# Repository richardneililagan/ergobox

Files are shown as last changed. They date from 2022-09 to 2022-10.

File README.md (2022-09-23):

Ergobox: Hitbox-style fightstick
===

> **NOTE: Work in progress.**
>
> This is not yet ready for build.

Ergobox is a low-profile hitbox-style fightstick based off of
[Flatbox rev4][flatbox-rev4].

This project wants to introduce the following changes / adjustments:

- a more ergonomic button layout
- RGB LED lighting
- adjustments to case to allow for easy personalization

while maintaining some key characteristics that make Flatbox great 
in my opinion:

- low-profile build using Kailh switches
- hotswappable switches
- USB-C port 
- no need for an addon board
- compatibility with [RP2040][rp2040] (so we can use, say, [GP2040-CE][gp2040ce] as firmware)
- ready-to-use artifacts for manufacturing

## Credits and thanks

I'd like to express my gratitude to the following projects,
which Ergobox uses as well:

- [Flatbox][flatbox]
- [keyswitch-kicad-library][keyswitch-kicad-library]
- [Type-C.pretty][typec-pretty]
- [CrumpPrints.pretty][crumpprints-pretty]

## License

This project is licensed under GPLv3.
See [LICENSE](./LICENSE) for the full license text.

[flatbox]: https://github.com/jfedor2/flatbox
[flatbox-rev4]: https://github.com/jfedor2/flatbox/tree/master/hardware-rev4
[rp2040]: https://www.raspberrypi.com/documentation/microcontrollers/rp2040.html
[gp2040ce]: https://github.com/OpenStickFoundation/GP2040-CE

[keyswitch-kicad-library]: https://github.com/perigoso/keyswitch-kicad-library
[typec-pretty]: https://github.com/ai03-2725/Type-C.pretty
[crumpprints-pretty]: https://github.com/tylercrumpton/CrumpPrints.pretty

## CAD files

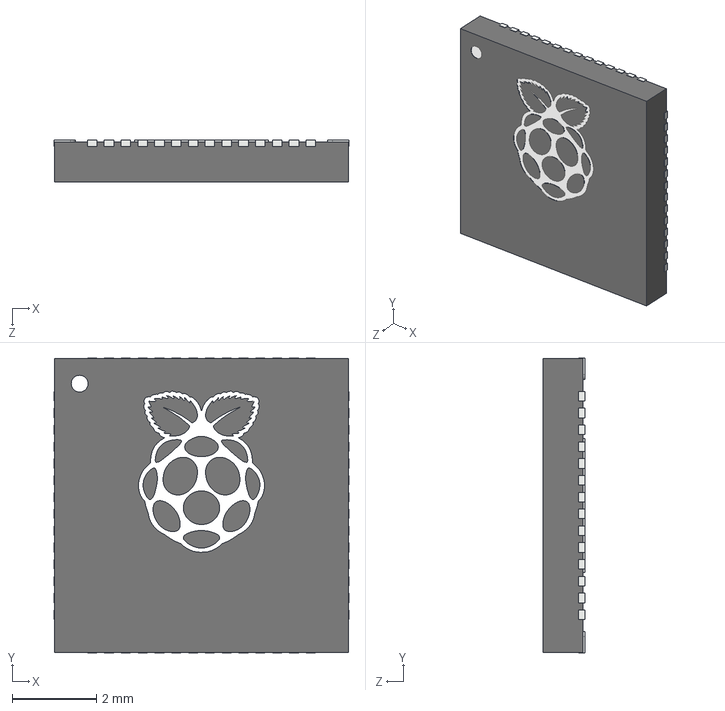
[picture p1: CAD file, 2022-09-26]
pcb/kicad/includes/models/RP2040_QFN_PACKAGE.STEP
7.02 x 7.02 x 1.00 mm

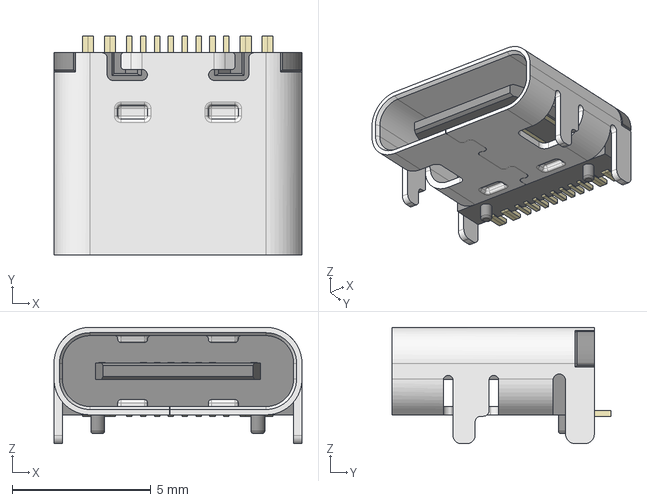
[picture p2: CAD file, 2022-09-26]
pcb/kicad/includes/models/HRO_TYPE-C-31-M-12.step
8.95 x 7.90 x 4.20 mm

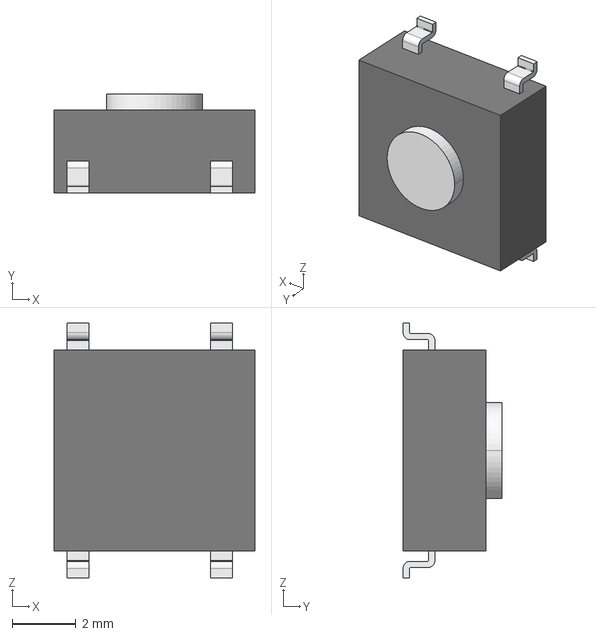
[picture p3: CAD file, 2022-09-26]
pcb/kicad/includes/models/b3fs-1000p.stp
6.30 x 3.10 x 8.00 mm

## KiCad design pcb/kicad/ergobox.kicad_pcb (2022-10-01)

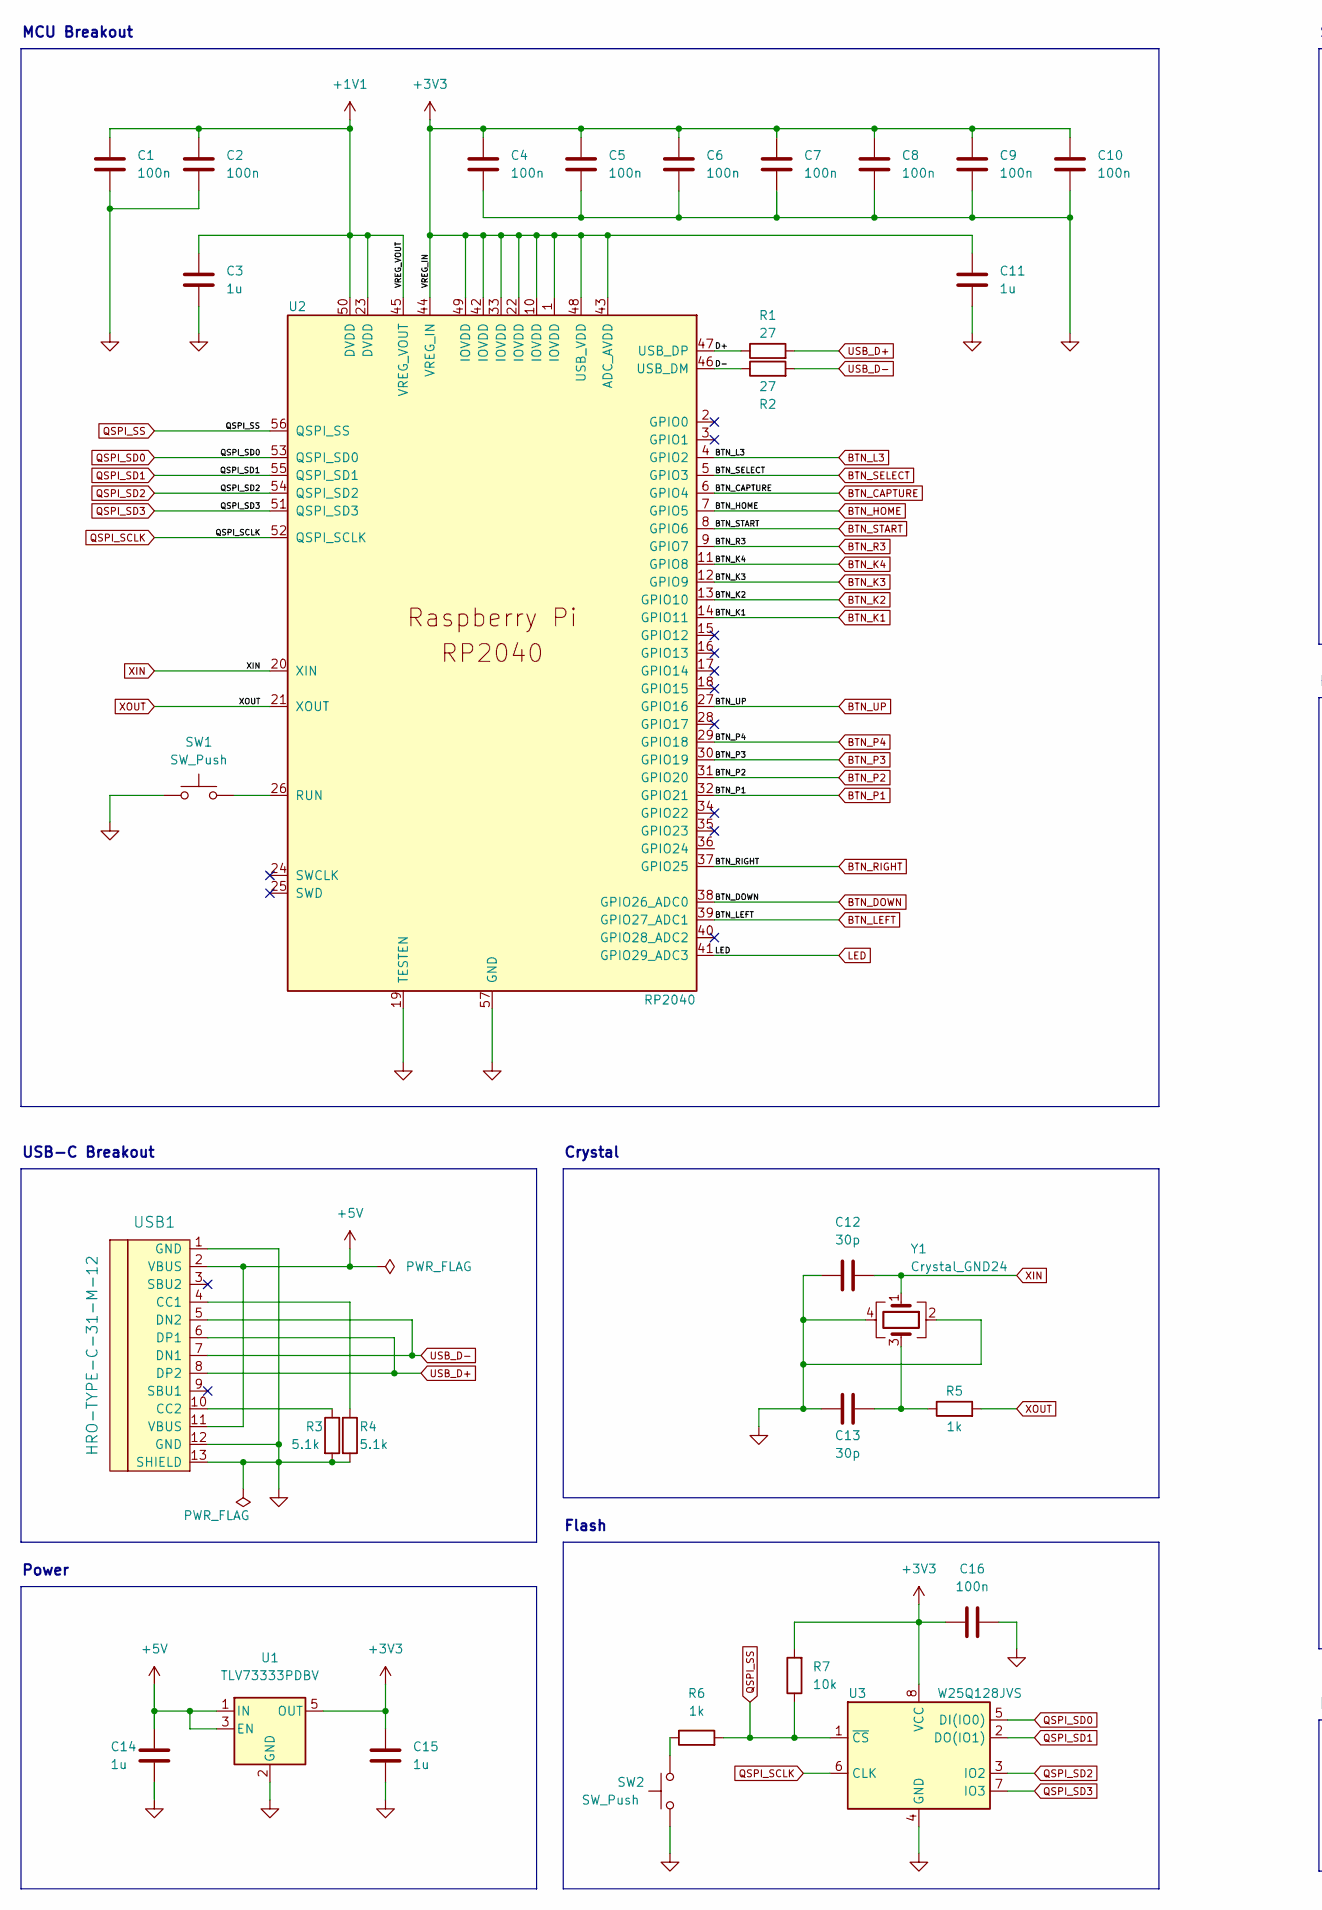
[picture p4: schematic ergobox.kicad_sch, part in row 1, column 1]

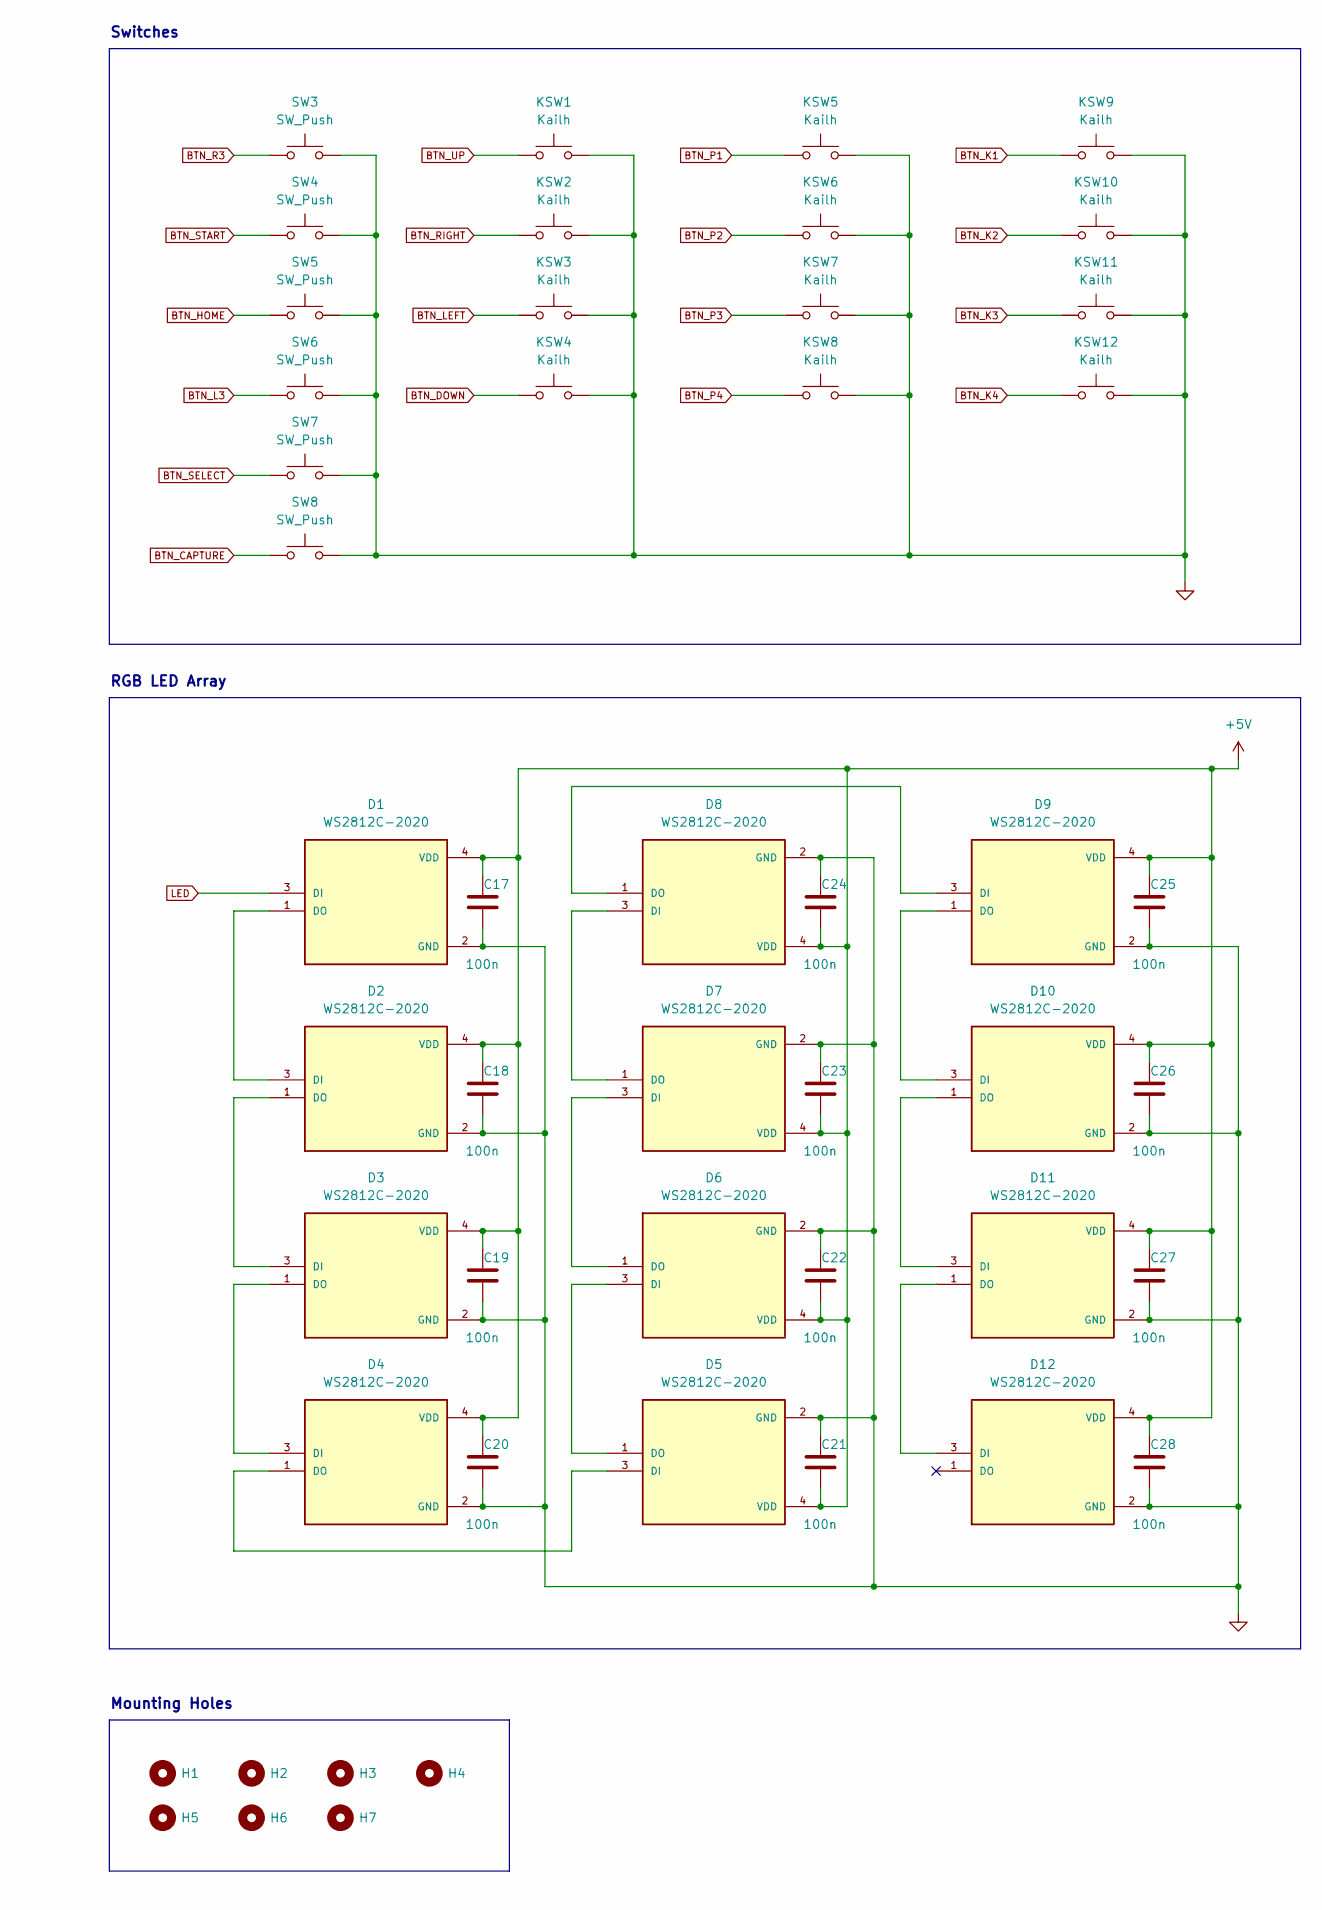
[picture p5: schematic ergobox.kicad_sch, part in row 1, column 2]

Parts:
C1, C2, C4, C5, C6, C7, C8, C9, C10, C16: 100n; C_0402_1005Metric; LCSC C1525
C3, C11, C14, C15: 1u; C_0402_1005Metric; LCSC C52923
C12, C13: 30p; C_0402_1005Metric; LCSC C1570
C17, C18, C19, C20, C21, C22, C23, C24, C25, C26, C27, C28: 100n; C_0402_1005Metric; LCSC C52923
D1, D2, D3, D4, D5, D6, D7, D8, D9, D10, D11, D12: WS2812C-2020; LED_WS2812C-2020; PARTREV V1.0; LCSC C2976072
H1, H2, H3, H4, H5, H6, H7: MountingHole; MountingHole_3.2mm_M3
KSW1, KSW2, KSW3, KSW4, KSW5, KSW6, KSW7, KSW8, KSW9, KSW10, KSW11, KSW12: Kailh; SW_Hotswap_Kailh_Choc_V1V2; JLCPCB_IGNORE true
R1, R2: 27; R_0402_1005Metric; LCSC C138021
R3, R4: 5.1k; R_0402_1005Metric; LCSC C25905
R5, R6: 1k; R_0402_1005Metric; LCSC C11702
R7: 10k; R_0402_1005Metric; LCSC C25744
SW1, SW2: SW_Push; SW_SPST_Omron_B3FS-100xP; LCSC C271750
SW3, SW4, SW5, SW6, SW7, SW8: SW_Push; SW_PUSH_6mm_H5mm; LCSC C620304
U1: TLV73333PDBV; SOT-23-5; LCSC C134139
U2: RP2040; RP2040-QFN-56; LCSC C2040
U3: W25Q128JVS; SOIC-8_5.23x5.23mm_P1.27mm; LCSC C97521
USB1: HRO-TYPE-C-31-M-12; LCSC C165948
Y1: Crystal_GND24; Crystal_SMD_3225-4Pin_3.2x2.5mm; LCSC C9002

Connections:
+1V1: C1.1, C2.1, C3.1, U2.23 (DVDD), U2.45 (VREG_VOUT), U2.50 (DVDD)
+3V3: C4.1, C5.1, C6.1, C7.1, C8.1, C9.1, C10.1, C11.1, C15.1, C16.1, R7.2, U1.5 (OUT), U2.1 (IOVDD), U2.10 (IOVDD), U2.22 (IOVDD), U2.33 (IOVDD), U2.42 (IOVDD), U2.43 (ADC_AVDD), U2.44 (VREG_IN), U2.48 (USB_VDD), U2.49 (IOVDD), U3.8 (VCC)
+5V: C14.1, C17.1, C18.1, C19.1, C20.1, C21.2, C22.2, C23.2, C24.2, C25.1, C26.1, C27.1, C28.1, D1.4 (VDD), D2.4 (VDD), D3.4 (VDD), D4.4 (VDD), D5.4 (VDD), D6.4 (VDD), D7.4 (VDD), D8.4 (VDD), D9.4 (VDD), D10.4 (VDD), D11.4 (VDD), D12.4 (VDD), U1.1 (IN), U1.3 (EN), USB1.2 (VBUS), USB1.11 (VBUS)
/D+: R1.1, U2.47 (USB_DP)
/D-: R2.1, U2.46 (USB_DM)
BTN_CAPTURE: SW8.1, U2.6 (GPIO4)
BTN_DOWN: KSW4.1, U2.38 (GPIO26_ADC0)
BTN_HOME: SW5.1, U2.7 (GPIO5)
BTN_K1: KSW9.1, U2.14 (GPIO11)
BTN_K2: KSW10.1, U2.13 (GPIO10)
BTN_K3: KSW11.1, U2.12 (GPIO9)
BTN_K4: KSW12.1, U2.11 (GPIO8)
BTN_L3: SW6.1, U2.4 (GPIO2)
BTN_LEFT: KSW3.1, U2.39 (GPIO27_ADC1)
BTN_P1: KSW5.1, U2.32 (GPIO21)
BTN_P2: KSW6.1, U2.31 (GPIO20)
BTN_P3: KSW7.1, U2.30 (GPIO19)
BTN_P4: KSW8.1, U2.29 (GPIO18)
BTN_R3: SW3.1, U2.9 (GPIO7)
BTN_RIGHT: KSW2.1, U2.37 (GPIO25)
BTN_SELECT: SW7.1, U2.5 (GPIO3)
BTN_START: SW4.1, U2.8 (GPIO6)
BTN_UP: KSW1.1, U2.27 (GPIO16)
GND: C1.2, C2.2, C3.2, C4.2, C5.2, C6.2, C7.2, C8.2, C9.2, C10.2, C11.2, C12.1, C13.1, C14.2, C15.2, C16.2, C17.2, C18.2, C19.2, C20.2, C21.1, C22.1, C23.1, C24.1, C25.2, C26.2, C27.2, C28.2, D1.2 (GND), D2.2 (GND), D3.2 (GND), D4.2 (GND), D5.2 (GND), D6.2 (GND), D7.2 (GND), D8.2 (GND), D9.2 (GND), D10.2 (GND), D11.2 (GND), D12.2 (GND), KSW1.2, KSW2.2, KSW3.2, KSW4.2, KSW5.2, KSW6.2, KSW7.2, KSW8.2, KSW9.2, KSW10.2, KSW11.2, KSW12.2, R3.2, R4.2, SW1.1, SW2.1, SW3.2, SW4.2, SW5.2, SW6.2, SW7.2, SW8.2, U1.2 (GND), U2.19 (TESTEN), U2.57 (GND), U3.4 (GND), USB1.1 (GND), USB1.12 (GND), USB1.13 (SHIELD), Y1.2, Y1.4
LED: D1.3 (DI), U2.41 (GPIO29_ADC3)
unnamed: C13.2, R5.1, Y1.3
unnamed: D1.1 (DO), D2.3 (DI)
unnamed: D2.1 (DO), D3.3 (DI)
unnamed: D3.1 (DO), D4.3 (DI)
unnamed: D4.1 (DO), D5.3 (DI)
unnamed: D5.1 (DO), D6.3 (DI)
unnamed: D6.1 (DO), D7.3 (DI)
unnamed: D7.1 (DO), D8.3 (DI)
unnamed: D8.1 (DO), D9.3 (DI)
unnamed: D10.1 (DO), D11.3 (DI)
unnamed: D9.1 (DO), D10.3 (DI)
unnamed: D11.1 (DO), D12.3 (DI)
unnamed: R3.1, USB1.10 (CC2)
unnamed: R4.1, USB1.4 (CC1)
unnamed: R6.1, SW2.2
unnamed: SW1.2, U2.26 (RUN)
QSPI_SCLK: U2.52 (QSPI_SCLK), U3.6 (CLK)
QSPI_SD0: U2.53 (QSPI_SD0), U3.5 (DI(IO0))
QSPI_SD1: U2.55 (QSPI_SD1), U3.2 (DO(IO1))
QSPI_SD2: U2.54 (QSPI_SD2), U3.3 (IO2)
QSPI_SD3: U2.51 (QSPI_SD3), U3.7 (IO3)
QSPI_SS: R6.2, R7.1, U2.56 (QSPI_SS), U3.1 (~CS)
USB_D+: R1.2, USB1.6 (DP1), USB1.8 (DP2)
USB_D-: R2.2, USB1.5 (DN2), USB1.7 (DN1)
XIN: C12.2, U2.20 (XIN), Y1.1
XOUT: R5.2, U2.21 (XOUT)

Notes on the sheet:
RGB LED Array
Flash
USB-C Breakout
Mounting Holes
Switches
Power
Crystal
MCU Breakout

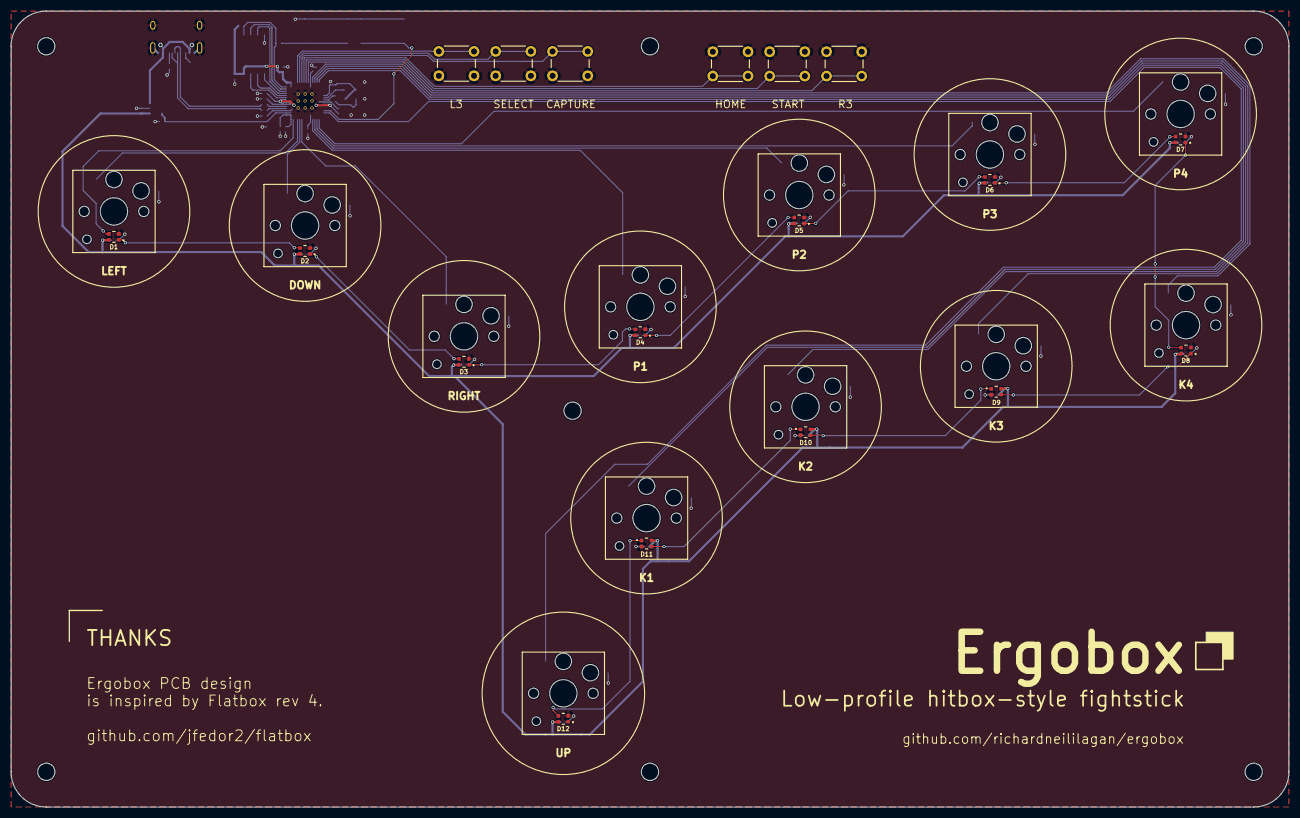
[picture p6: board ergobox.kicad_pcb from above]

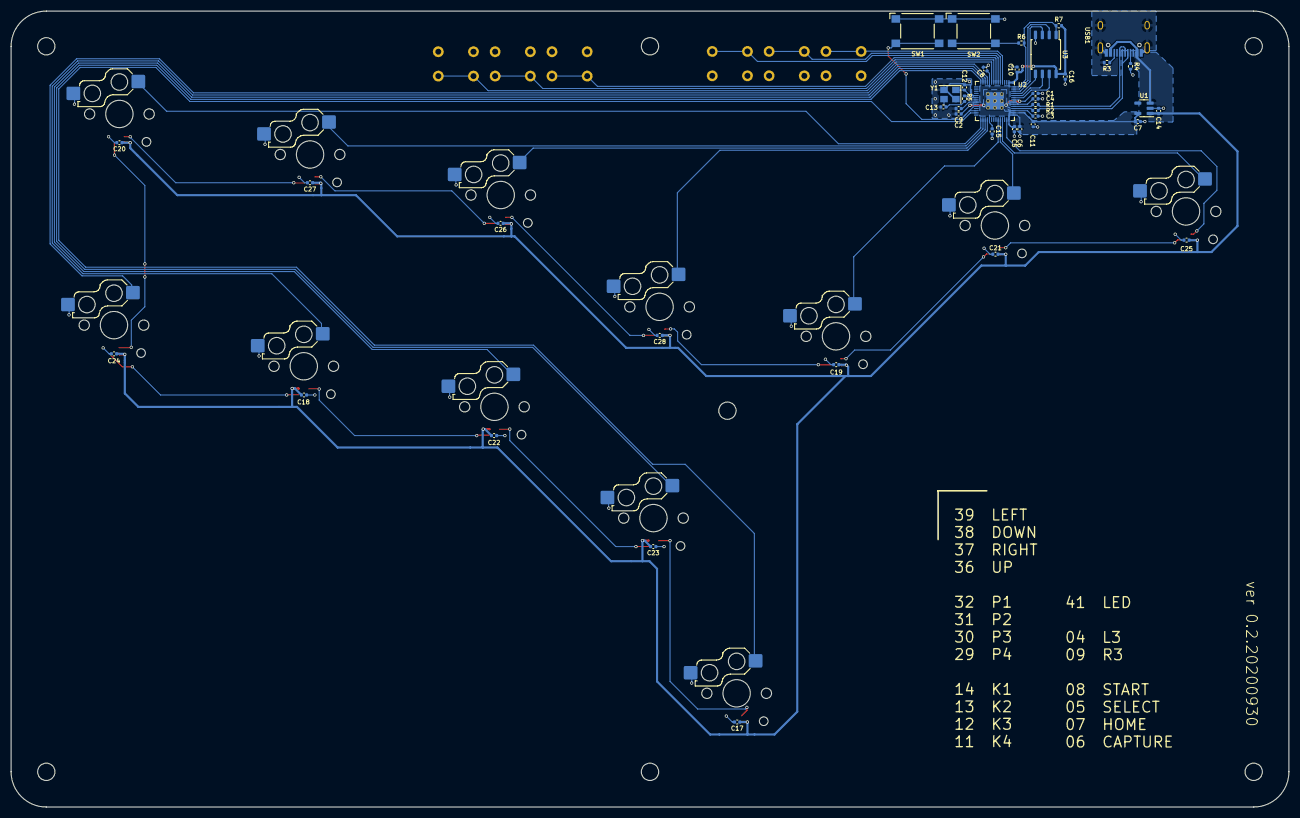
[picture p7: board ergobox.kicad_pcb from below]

Board: 2 copper layers, 236.0 x 147.0 mm, 79 parts (42 on the bottom side), 51 nets.

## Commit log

2022-09-23 chore: adds initial includes
    [ergobox.kicad_sch]
2022-09-23 feat: adds initial schematic design
    [ergobox.kicad_sch]
2022-09-23 feat: updates footprints for Kailh switches and WS2812C-2020
    [ergobox.kicad_sch]
2022-09-23 feat: adds footprints to remaining components
    [ergobox.kicad_sch]
2022-09-23 refactor: changes footprint for Kailh switches to 1350_optional
    [ergobox.kicad_sch]
2022-09-23 feat: adds M4 mounting holes to schematic
    [ergobox.kicad_sch]
2022-09-24 feat: initial PCB setup
    [ergobox.kicad_pcb, ergobox.kicad_sch]
2022-09-24 refactor: adjusts initial PCB layout to match viewlix specs
    [ergobox.kicad_pcb]
2022-09-25 feat: places kailh switches on PCB
    [ergobox.kicad_pcb]
2022-09-25 refactor: changes kailh footprints to hotswap non-optionals.
    The kailh low footprints with optional hotswaps are not symmetric.
    In the optional footprint, the hotswap switch pad goes through the RGB footpad,
    so it cannot be used.
    [ergobox.kicad_pcb, ergobox.kicad_sch]
2022-09-25 feat: places per-key RGB LEDs on PCB
    [ergobox.kicad_pcb]
2022-09-25 feat: introduces GND plane on B.Cu
    [ergobox.kicad_pcb, ergobox.kicad_sch]
2022-09-25 feat: checkin milestone
    [ergobox.kicad_pcb, ergobox.kicad_sch]
2022-09-26 feat: initial lay out for flash and power
    [ergobox.kicad_pcb]
2022-09-26 feat: adds +3V3 copper fill in RP2040 footprint
    [ergobox.kicad_pcb]
2022-09-26 fix: adjusts copper fills
    [ergobox.kicad_pcb]
2022-09-26 feat: initial completed PCB layout
    [ergobox.kicad_pcb]
2022-09-26 chore: adjusts aesthetics
    [ergobox.kicad_pcb]
2022-09-26 feat: adds Omron B3FS-1000P CAD model
    [b3fs-1000p.stp, ergobox.kicad_pcb]
2022-09-26 feat: adds USB-C port CAD model
    [HRO_TYPE-C-31-M-12.step]
2022-09-26 feat: adds RP2040 and Kailh switch CAD models
    [RP2040_QFN_PACKAGE.STEP, ergobox.kicad_pcb]
2022-09-26 fix: corrects 3d model for SOIC flash
    [ergobox.kicad_pcb]
2022-09-27 refactor: adjusts design to grid origin
    [ergobox.kicad_pcb]
2022-09-27 refactor: updates PCB model to use STEP models instead of WRL
    [ergobox.kicad_pcb]
2022-09-30 refactor: creates Ergobox v0.2 PCB design, with most SMD components on the underside
    [ergobox.kicad_pcb, ergobox.kicad_sch]
2022-09-30 chore: adds silkscreen boundaries for circular arcade buttons
    [ergobox.kicad_pcb]
2022-09-30 chore: adds silkscreen labels for aux buttons
    [ergobox.kicad_pcb]
2022-09-30 chore: adds GPIO pin numbers for button assignments to B.Silkscreen
    [ergobox.kicad_pcb]
2022-09-30 fix: adds LED data GPIO pin to B.Silkscreen legend
    [ergobox.kicad_pcb]
2022-09-30 chore: adds aesthetic elements to PCB design
    [ergobox.kicad_pcb]
2022-09-30 chore: adds JLCPCB part numbers to symbol fields
    [ergobox.kicad_sch]
2022-09-30 chore: adjusts schematic and PCB metadata for BOM/POS export
    [ergobox.kicad_pcb, ergobox.kicad_sch]
2022-10-01 chore: adds make command for generating pcb fab artifacts
    [ergobox.kicad_pcb, ergobox.kicad_sch]
2022-10-01 chore: prep for 3d modeling
    [ergobox.kicad_pcb]
2025-05-06 chore: adds kicad project
